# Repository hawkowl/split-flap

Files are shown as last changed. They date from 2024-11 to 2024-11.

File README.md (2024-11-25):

# Split-Flap

This repository contains:

- `PCB/Unit`, comprising of the PCB for the per-module controller
- `Unit/`, comprising of the firmware for the individual module controller
- `Controller/`, comprising of the firmware for a RP2040 controller for multiple modules

## Sources

- Original Design: [Split Flap Display by David Kingsman](https://www.printables.com/model/69464-split-flap-display).
- Flaps: [OpenSCAD flaps by rtitmuss](https://github.com/rtitmuss/splitflap/tree/main/OpenSCAD)
- Frame: [Modification by rtitmuss](https://www.printables.com/model/518882-split-flap-frame)

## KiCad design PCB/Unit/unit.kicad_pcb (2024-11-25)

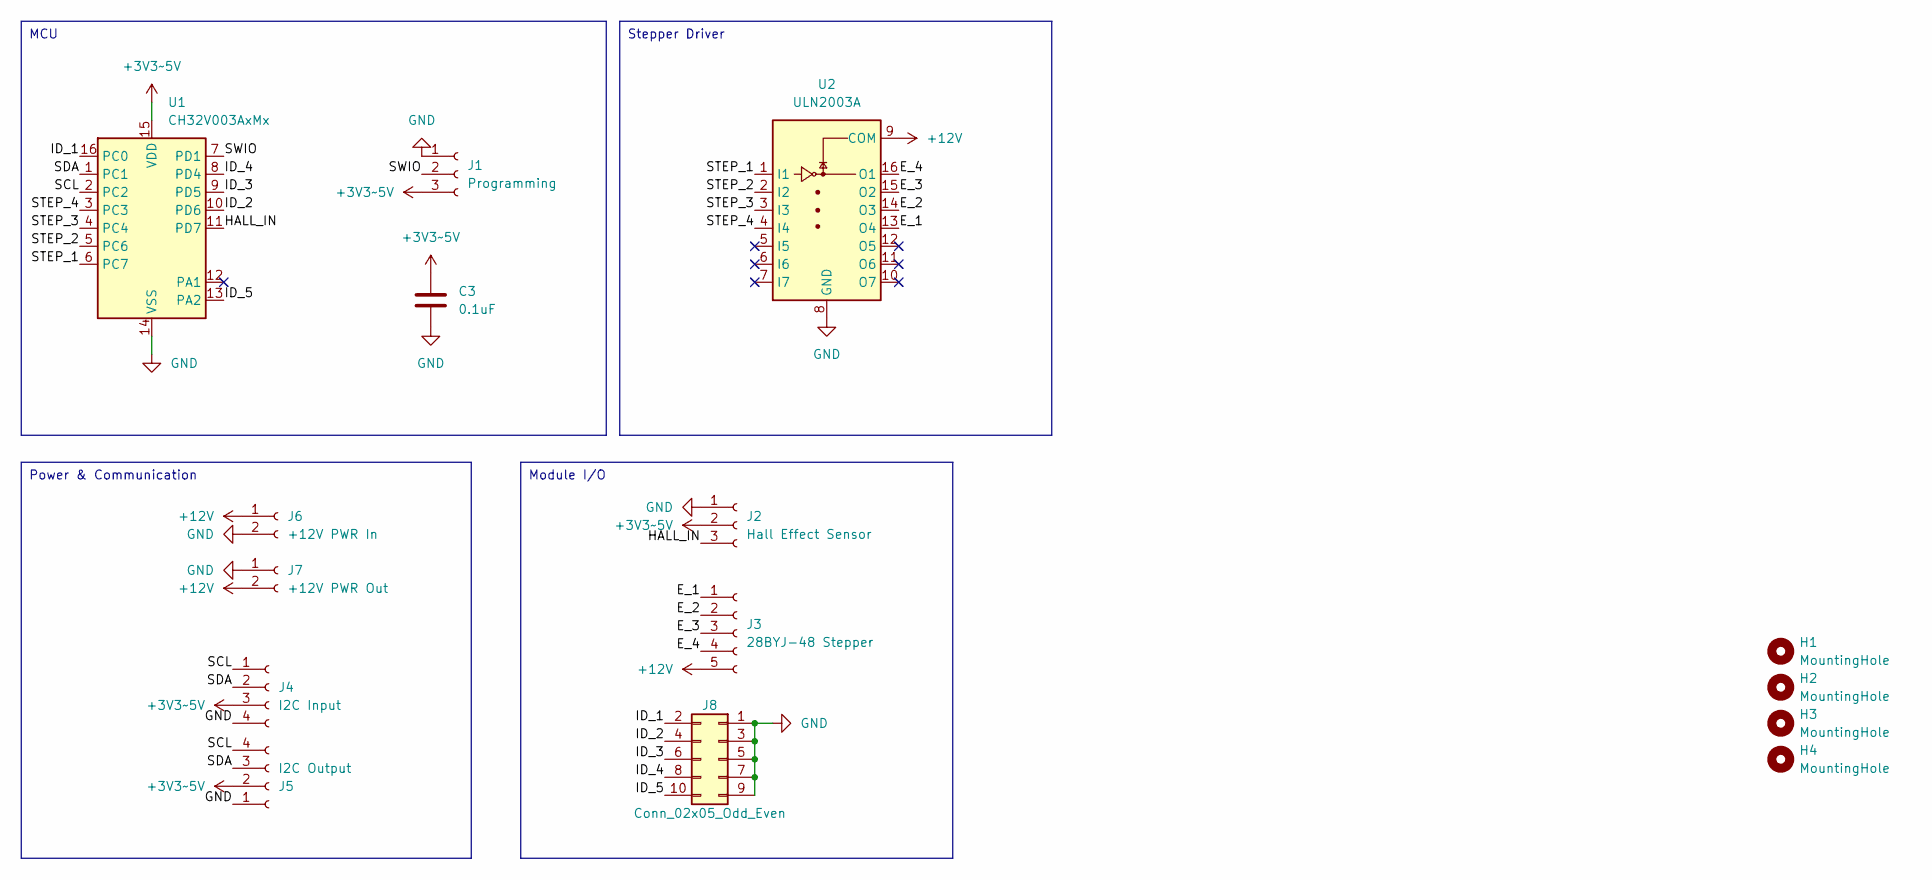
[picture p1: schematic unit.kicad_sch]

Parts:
C3: 0.1uF; C_1206_3216Metric_Symbol
H1, H2, H3, H4: MountingHole; MountingHole_3.2mm_M3
J1: Programming; JST_XH_B3B-XH-A_1x03_P2.50mm_Vertical
J2: Hall Effect Sensor; JST_XH_B3B-XH-A_1x03_P2.50mm_Vertical
J3: 28BYJ-48 Stepper; JST_XH_B5B-XH-A_1x05_P2.50mm_Vertical_LABELLED
J4: I2C Input; JST_XH_B4B-XH-A_1x04_P2.50mm_Vertical_LABELLED
J5: I2C Output; JST_XH_B4B-XH-A_1x04_P2.50mm_Vertical_LABELLED
J6: +12V PWR In; JST_XH_B2B-XH-A_1x02_P2.50mm_Vertical_LABELLED
J7: +12V PWR Out; JST_XH_B2B-XH-A_1x02_P2.50mm_Vertical_LABELLED
J8: Conn_02x05_Odd_Even; PinSocket_2x05_P2.54mm_Vertical
U1: CH32V003AxMx; SOP-16_3.9x9.9mm_P1.27mm
U2: ULN2003A; SOP-16_3.9x9.9mm_P1.27mm

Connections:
+3V3~5V: C3.2, J1.3, J2.2, J4.3, J5.2, U1.15 (VDD)
+12V: J3.5, J6.1, J7.2, U2.9 (COM)
/E_1: J3.1, U2.13 (O4)
/E_2: J3.2, U2.14 (O3)
/E_3: J3.3, U2.15 (O2)
/E_4: J3.4, U2.16 (O1)
/HALL_IN: J2.3, U1.11 (PD7)
/ID_1: J8.2, U1.16 (PC0)
/ID_2: J8.4, U1.10 (PD6)
/ID_3: J8.6, U1.9 (PD5)
/ID_4: J8.8, U1.8 (PD4)
/ID_5: J8.10, U1.13 (PA2)
/SCL: J4.1, J5.4, U1.2 (PC2)
/SDA: J4.2, J5.3, U1.1 (PC1)
/STEP_1: U1.6 (PC7), U2.1 (I1)
/STEP_2: U1.5 (PC6), U2.2 (I2)
/STEP_3: U1.4 (PC4), U2.3 (I3)
/STEP_4: U1.3 (PC3), U2.4 (I4)
/SWIO: J1.2, U1.7 (PD1)
GND: C3.1, J1.1, J2.1, J4.4, J5.1, J6.2, J7.1, J8.1, J8.3, J8.5, J8.7, J8.9, U1.14 (VSS), U2.8 (GND)

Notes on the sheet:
Module I/O
MCU
Power & Communication
Stepper Driver

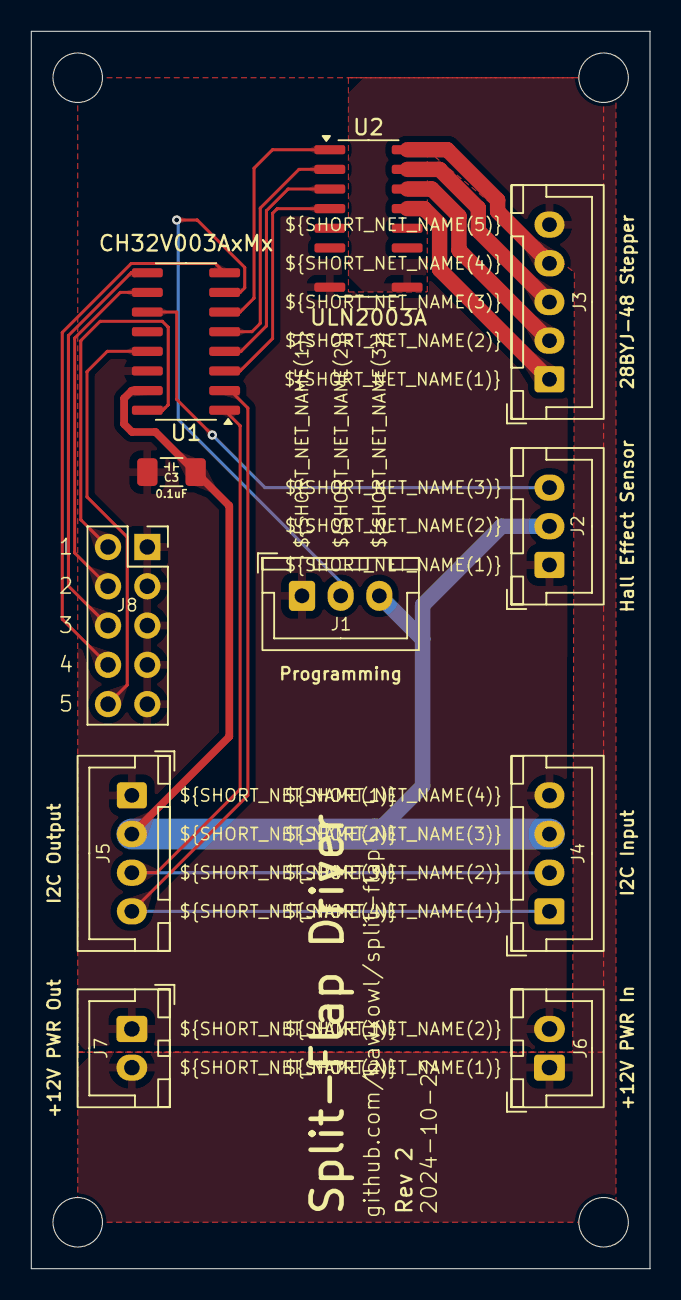
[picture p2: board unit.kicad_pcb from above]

Board: 2 copper layers, 40.0 x 80.0 mm, 15 parts (0 on the bottom side), 20 nets.

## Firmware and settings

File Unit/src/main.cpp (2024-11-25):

// Based off https://github.com/davidkingsman/split-flap 's Unit.ino

#include "main.hpp"

#include <Arduino.h>
#include <Stepper.h>
#include <ch32v003fun.h>
#include <i2c_slave.h>
#include <stdio.h>

#define SERIAL_ENABLE  // uncomment for serial debug communication

// Pins of I2C address switch
#define ADRESSSW4 PC0
#define ADRESSSW3 PD6
#define ADRESSSW2 PD5
#define ADRESSSW1 PD4

// constants stepper
#define STEPPERPIN1 PC6
#define STEPPERPIN2 PC7
#define STEPPERPIN3 PC3
#define STEPPERPIN4 PC4
#define HALLPIN PD7

#define STEPS 2038  // 28BYJ-48 stepper, number of steps
#define AMOUNTFLAPS 45

// constants others
#define ROTATIONDIRECTION -1  //-1 for reverse direction
#define OVERHEATINGTIMEOUT \
  2  // timeout in seconds to avoid overheating of stepper-> After starting
     // rotation, the counter will start. Stepper won't move again until timeout
     // is passed
unsigned long lastRotation = 0;

// globals
int displayedLetter = 0;  // currently shown letter
int desiredLetter = 0;    // letter to be shown
const char* letters[] = {
    " ", "A", "B", "C", "D", "E", "F", "G", "H", "I", "J", "K", "L", "M", "N",
    "O", "P", "Q", "R", "S", "T", "U", "V", "W", "X", "Y", "Z", "Ä", "Ö", "Ü",
    "0", "1", "2", "3", "4", "5", "6", "7", "8", "9", ":", ".", "-", "?", "!"};
Stepper* stepper;

PinStatus lastInd1 = LOW;  // store last status of phase
PinStatus lastInd2 = LOW;  // store last status of phase
PinStatus lastInd3 = LOW;  // store last status of phase
PinStatus lastInd4 = LOW;  // store last status of phase
float missedSteps = 0;  // cummulate steps <1, to compensate via additional step
                        // when reaching >1
int currentlyrotating =
    0;  // 1 = drum is currently rotating, 0 = drum is standing still
int stepperSpeed = 10;  // current speed of stepper, value only for first homing
int calOffset = 74;     // Offset for calibration in steps
int receivedNumber = 0;
bool doCalibrate = false;
int i2cAddress;

// sleep globals
const unsigned long WAIT_TIME =
    100;  // wait time before sleep routine gets executed again in milliseconds
unsigned long previousMillis = 0;  // stores last time sleep was interrupted

volatile uint8_t i2c_registers[32] = {0x00};

// setup
void setup() {
  funGpioInitAll();

  stepper = new Stepper(STEPS, STEPPERPIN1, STEPPERPIN3, STEPPERPIN2,
                        STEPPERPIN4);  // stepper setup

  pinMode(STEPPERPIN1, OUTPUT);
  pinMode(STEPPERPIN2, OUTPUT);
  pinMode(STEPPERPIN3, OUTPUT);
  pinMode(STEPPERPIN4, OUTPUT);

#ifdef SERIAL_ENABLE
  printf("starting unit...\n");
#endif

  // i2c address switch
  pinMode(ADRESSSW1, INPUT_PULLUP);
  pinMode(ADRESSSW2, INPUT_PULLUP);
  pinMode(ADRESSSW3, INPUT_PULLUP);
  pinMode(ADRESSSW4, INPUT_PULLUP);

  // hall sensor
  pinMode(HALLPIN, INPUT);

  i2cAddress = getaddress();  // get I2C Address and save in variable

#ifdef SERIAL_ENABLE
  printf("I2CAddress: %d\n", i2cAddress);
#endif

  funPinMode(PC1, GPIO_CFGLR_OUT_10Mhz_AF_OD);  // SDA
  funPinMode(PC2, GPIO_CFGLR_OUT_10Mhz_AF_OD);  // SCL

  SetupI2CSlave(i2cAddress, i2c_registers, sizeof(i2c_registers), receiveLetter,
                requestEvent, false);
}

void loop() {
  // If we need to recalibrate, do that now
  if (doCalibrate) {
    printf("Doing initial calibration\n");
    doCalibrate = false;
    calibrate(true);
  }

  unsigned long currentMillis = millis();
  if (currentMillis - previousMillis >= WAIT_TIME) {
    delay(WAIT_TIME);
  }  // end of time to sleep

  previousMillis = millis();  // reset sleep counter

  if (displayedLetter != receivedNumber) {
#ifdef SERIAL_ENABLE
    printf("Value over serial received: %d Letter: %s @ speed %d\n",
           receivedNumber, letters[receivedNumber], stepperSpeed);
#endif
    // rotate to new letter
    rotateToLetter(receivedNumber);
  }
}

// rotate to letter
void rotateToLetter(int toLetter) {
  if (lastRotation == 0 ||
      (millis() - lastRotation > OVERHEATINGTIMEOUT * 1000)) {
    lastRotation = millis();
    // get letter position
    int posLetter = -1;
    posLetter = toLetter;
    int posCurrentLetter = -1;
    posCurrentLetter = displayedLetter;
    // int amountLetters = sizeof(letters) / sizeof(String);
#ifdef SERIAL_ENABLE
    printf("go to letter: %s\n", letters[toLetter]);
#endif
    // go to letter, but only if available (>-1)
    if (posLetter > -1) {  // check if letter exists
      // check if letter is on higher index, then no full rotaion is needed
      if (posLetter >= posCurrentLetter) {
#ifdef SERIAL_ENABLE
        printf("direct\n");
#endif
        // go directly to next letter, get steps from current letter to target
        // letter
        int diffPosition = posLetter - posCurrentLetter;
        startMotor();
        stepper->setSpeed(stepperSpeed);
        // doing the rotation letterwise
        for (int i = 0; i < diffPosition; i++) {
          float preciseStep = (float)STEPS / (float)AMOUNTFLAPS;
          int roundedStep = (int)preciseStep;
          missedSteps = missedSteps + ((float)preciseStep - (float)roundedStep);
          if (missedSteps > 1) {
            roundedStep = roundedStep + 1;
            missedSteps--;
          }
          stepper->step(ROTATIONDIRECTION * roundedStep);
        }
      } else {
        // full rotation is needed, good time for a calibration
#ifdef SERIAL_ENABLE
        printf("full rotation incl. calibration\n");
#endif
        calibrate(false);  // calibrate revolver and do not stop motor
        // startMotor();
        stepper->setSpeed(stepperSpeed);
        for (int i = 0; i < posLetter; i++) {
          float preciseStep = (float)STEPS / (float)AMOUNTFLAPS;
          int roundedStep = (int)preciseStep;
          missedSteps = missedSteps + (float)preciseStep - (float)roundedStep;
          if (missedSteps > 1) {
            roundedStep = roundedStep + 1;
            missedSteps--;
          }
          stepper->step(ROTATIONDIRECTION * roundedStep);
        }
      }
      // store new position
      displayedLetter = toLetter;
      // rotation is done, stop the motor
      delay(100);  // important to stop rotation before shutting of the motor to
                   // avoid rotation after switching off current
      stopMotor();
    } else {
#ifdef SERIAL_ENABLE
      printf("letter unknown, go to space\n");
#endif
      desiredLetter = 0;
    }
  }
}

int oldOffset = 0;

void receiveLetter(uint8_t reg, uint8_t length) {
  printf("reg %d over i2c, length %d\n", reg, length);

  switch (reg) {
    case 0x01:
      receivedNumber = i2c_registers[reg];
      printf("set recv number to %d\n", receivedNumber);
      break;
    case 0x02:
      oldOffset = calOffset;
      calOffset = i2c_registers[reg];
      if (calOffset != oldOffset) {
        doCalibrate = true;
        printf("set cal offset to %d\n", calOffset);
      }
      break;
    default:
      break;
  }
  return;
}

void requestEvent(uint8_t reg) {
  printf("reading value over i2c %d\n", reg);

  switch (reg) {
    case 0x03:
      printf("rotating over i2c = %d\n", currentlyrotating);
      i2c_registers[reg] = currentlyrotating;
      break;
    default:
      break;
  }
  return;
}

// returns the adress of the unit as int from 0-15
int getaddress() {
  int address = !digitalRead(ADRESSSW4) + (!digitalRead(ADRESSSW3) * 2) +
                (!digitalRead(ADRESSSW2) * 4) + (!digitalRead(ADRESSSW1) * 8);
  return address;
}

// doing a calibration of the revolver using the hall sensor
int calibrate(bool initialCalibration) {
#ifdef SERIAL_ENABLE
  printf("calibrate revolver\n");
#endif
  currentlyrotating = 1;  // set active state to active
  bool reachedMarker = false;
  stepper->setSpeed(stepperSpeed);
  int i = 0;
  while (!reachedMarker) {
    int currentHallValue = digitalRead(HALLPIN);
    if (currentHallValue == 1 && i == 0) {  // already in zero position move out
                                            // a bit and do the calibration {
      // not reached yet
      i = 50;
      stepper->step(ROTATIONDIRECTION *
                    50);  // move 50 steps to get out of scope of hall
    } else if (currentHallValue == 1) {
      // not reached yet
      stepper->step(ROTATIONDIRECTION * 1);
    } else {
      // reached marker, go to calibrated offset position
      reachedMarker = true;
      stepper->step(ROTATIONDIRECTION * calOffset);
      displayedLetter = 0;
      missedSteps = 0;
#ifdef SERIAL_ENABLE
      printf("revolver calibrated\n");
#endif
      // Only stop motor for initial calibration
      if (initialCalibration) {
        stopMotor();
      }
      return i;
    }
    if (i > 3 * STEPS) {
      // seems that there is a problem with the marker or the sensor. turn off
      // the motor to avoid overheating.
      displayedLetter = 0;
      desiredLetter = 0;
      reachedMarker = true;
#ifdef SERIAL_ENABLE
      printf("calibration revolver failed\n");
#endif
      stopMotor();
      return -1;
    }
    i++;
  }
  return i;
}

// switching off the motor driver
void stopMotor() {
  lastInd1 = digitalRead(STEPPERPIN1);
  lastInd2 = digitalRead(STEPPERPIN2);
  lastInd3 = digitalRead(STEPPERPIN3);
  lastInd4 = digitalRead(STEPPERPIN4);

  digitalWrite(STEPPERPIN1, LOW);
  digitalWrite(STEPPERPIN2, LOW);
  digitalWrite(STEPPERPIN3, LOW);
  digitalWrite(STEPPERPIN4, LOW);
#ifdef SERIAL_ENABLE
  printf("Motor Stop\n");
#endif
  currentlyrotating = 0;  // set active state to not active
  delay(100);
}

void startMotor() {
#ifdef SERIAL_ENABLE
  printf("Motor Start\n");
#endif
  currentlyrotating = 1;  // set active state to active
  digitalWrite(STEPPERPIN1, lastInd1);
  digitalWrite(STEPPERPIN2, lastInd2);
  digitalWrite(STEPPERPIN3, lastInd3);
  digitalWrite(STEPPERPIN4, lastInd4);
}

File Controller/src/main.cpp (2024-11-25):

#include <Arduino.h>
#include <Wire.h>

#include "SafeString.h"
#include "SafeStringReader.h"

const int FLAPAMOUNT = 53;

const int CALIBRATION_VALS[] = {
    73,
    73,
    70,
};

const int UNITS = 3;

const char* letters[] = {
    " ", "A", "B", "C", "D", "E", "F", "G", "H", "I", "J", "K", "L", "M", "N",
    "O", "P", "Q", "R", "S", "T", "U", "V", "W", "X", "Y", "Z", "Ä", "Ö", "Ü",
    "0", "1", "2", "3", "4", "5", "6", "7", "8", "9", ":", ".", "-", "?", "!"};

String text = "";
int textcount = 0;

createSafeStringReader(sfReader, 10, "\r\n");

int idx = 0;

// translates char to letter position
int translateLettertoInt(char letterchar) {
  for (int i = 0; i < FLAPAMOUNT; i++) {
    if (letterchar == *letters[i]) {
      return i;
    }
  }
  return -1;
}

void transmitLetter(int target, char letter) {
  Serial.printf(
      "UNIT %d: sending %c to unit @ speed 10, calibration offset %d\n", target,
      letter, CALIBRATION_VALS[target - 1]);
  Wire1.beginTransmission(target);
  Wire1.write(0x02);
  Wire1.write(CALIBRATION_VALS[target - 1]);
  Wire1.endTransmission();

  Wire1.beginTransmission(target);
  Wire1.write(0x01);
  Wire1.write(translateLettertoInt(letter));
  Wire1.endTransmission();

  Wire1.flush();
}

bool getTurning(int target) {
  Serial.printf("UNIT %d: checking turning\n", target);

  byte out;

  Wire1.beginTransmission(target);
  Wire1.write(0x03);
  Wire1.endTransmission();

  Wire1.requestFrom(target, 0x01);
  while (Wire1.available()) {
    out = Wire1.read();
  }

  Serial.printf("UNIT %d: got %d\n", target, out);
  return out == 0;
}

void waitForStopped() {
  // Wait for it to settle
  delay(250);

  for (int i = 1; i < UNITS + 1; i++) {
    while (!getTurning(i)) {
      delay(250);
    }
  }
  Serial.printf("all units stopped!\n");
}

void reset() {
  for (int i = 0; i < UNITS; i++) {
    transmitLetter(i + 1, ' ');
  }
}

void setup() {
  Serial.begin();

  SafeString::setOutput(Serial);
  sfReader.connect(Serial);
  sfReader.echoOn();

  Wire1.setClock(100000);
  Wire1.begin();

  delay(2500);

  reset();
  waitForStopped();

  delay(5000);

  Serial.println("off we go");
}

void loop() {
  if (sfReader.read()) {
    textcount = sfReader.length();
    text = sfReader.c_str();
    text.toUpperCase();
  }

  for (int i = 0; i < UNITS; i++) {
    char letter = ' ';

    if (idx + i < textcount) {
      letter = text[idx + i];
    }

    transmitLetter(i + 1, letter);
  }
  waitForStopped();

  if (textcount > 0) {
    idx = idx + UNITS;
    if (idx >= textcount) {
      idx = 0;
      delay(7500);
      reset();
      textcount = 0;
    } else {
      delay(7500);
    }
  }
}
